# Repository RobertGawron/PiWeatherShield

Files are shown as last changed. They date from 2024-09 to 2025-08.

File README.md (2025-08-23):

# Pi Weather Shield



## Purpose

Low-cost, easy-to-build hat Raspberry Pi that turns it into an indoor weather station. On the hardware side, it's a simple PCB with sensors I2C parts (BME280 and Si7021) and a small OLED screen to show the meassurements: temperature, humidity, and air pressure. On the software side there is a Rust app that handles the data and can send them via MQTT for furthr processing (using tools like Graphana and Home asistant).

The project can be integrated with the [Home Environment Monitor](https://github.com/RobertGawron/HomeEnvironmentMonitor), adding real-time graphs of the meassurements accessible from phone or PC.

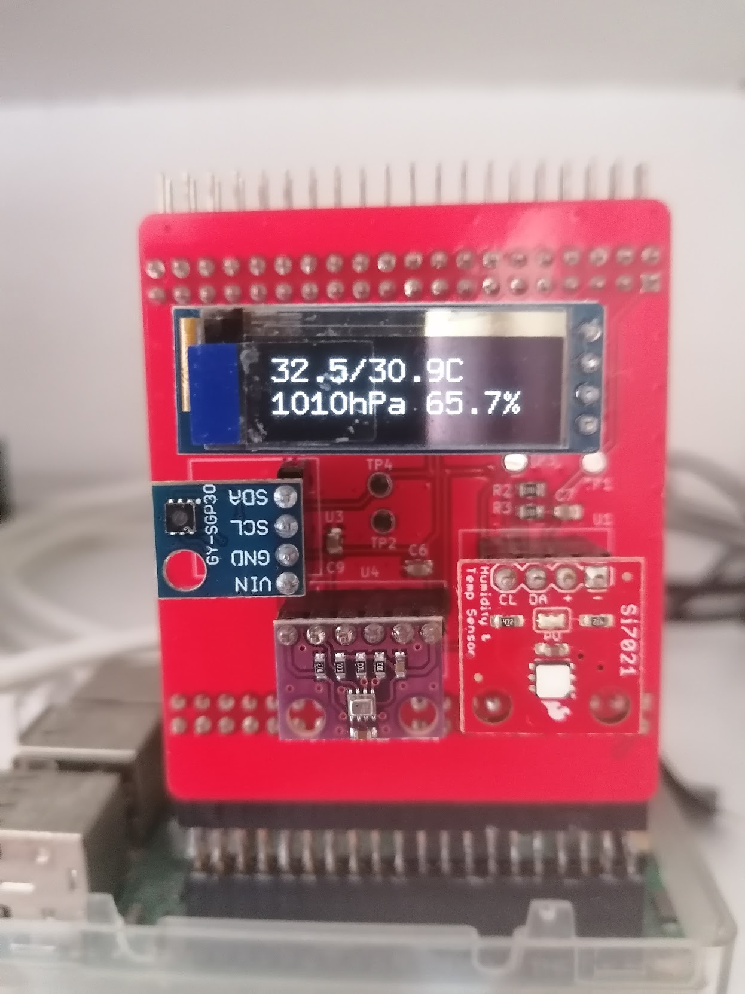
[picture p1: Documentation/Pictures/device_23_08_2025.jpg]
Picture of the device


## Hardware

This project is straightforward and includes the following I2C components:

* **Si7021:**
    * Temperature
    * Relative humidity
* **SGP30:**
    * TVOC (Total Volatile Organic Compounds)
    * eCO2 (equivalent CO2)
    * Raw hydrogen (H2) signal
    * Raw ethanol signal
* **BME280:**
    * Temperature
    * Relative humidity
    * Atmospheric pressure
* **SSD1306:** 0.91-inch 128x32 OLED display.

Circuit of the device

Tools: KiCad.

[More info.](./Hardware/README.md)

## Installation

The application is quite simple (just a couple of Python scripts) and could easily be developed directly on the Raspberry Pi, which is probably what most people would do for a small project like this. However, I’ve chosen a different approach -one that might seem like overkill- but it allows me to learn and apply DevOps.

We'll set up a local Docker environment capable of cross-compiling Docker images that contain our application, which will then be deployed to the Raspberry Pi.

Using Ansible, we will preconfigure the Raspberry Pi (install Docker, enable I2C, etc.) and deploy the Docker images to the Pi automatically.

[More info.](./DevOps/README.md)

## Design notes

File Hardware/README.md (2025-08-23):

## Hardware Overview

#### I2C Addresses:

* Si7021: 0x40
* SGP30: 0x58
* BME280:
    * 0x76 (when the SDO pin is grounded)
    * 0x77 (when the SDO pin is connected to VCC)
* SSD1306: 0x3C or 0x3D, depending on the PCB design.

## Tools

The PCB diagram was designed using KiCad.

## Links

* [Raspberry Pi pinout](https://www.raspberrypi.com/documentation/computers/images/GPIO-Pinout-Diagram-2.png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)

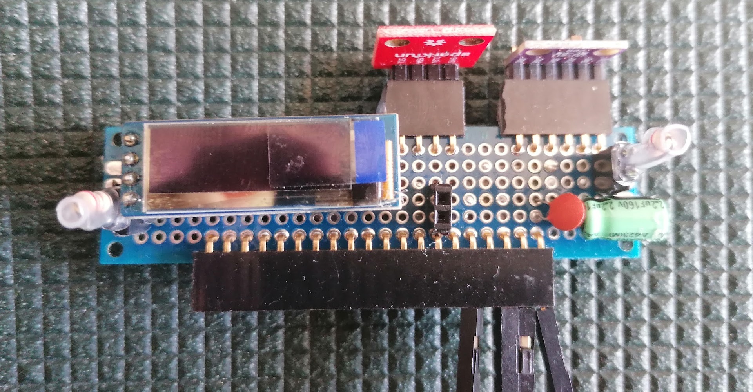
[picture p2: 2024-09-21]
Documentation/Pictures/device_21_09_2024.jpg

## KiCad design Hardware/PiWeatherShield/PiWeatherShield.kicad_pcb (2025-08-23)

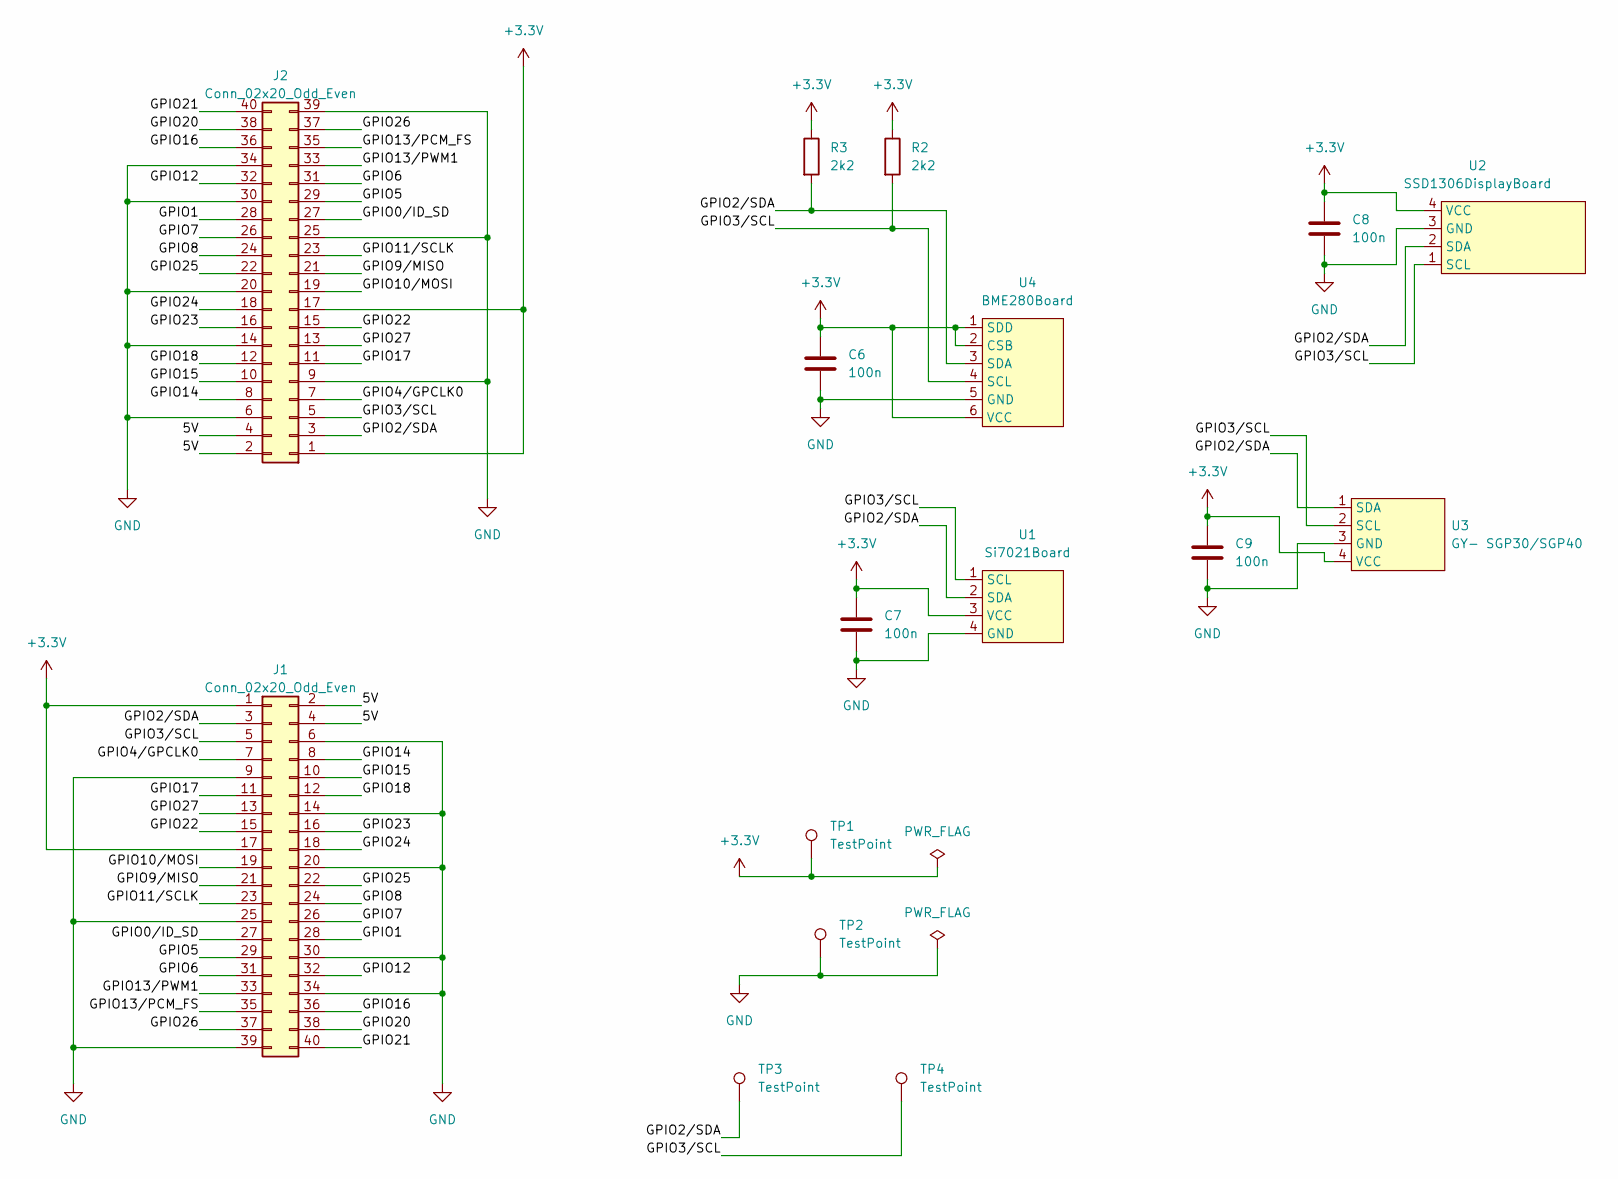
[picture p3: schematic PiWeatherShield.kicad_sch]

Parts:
C6, C7, C8, C9: 100n; C_0805_2012Metric
J1: Conn_02x20_Odd_Even; PinSocket_2x20_P2.54mm_Horizontal
J2: Conn_02x20_Odd_Even; PinHeader_2x20_P2.54mm_Horizontal
R2, R3: 2k2; R_0805_2012Metric
TP1, TP2, TP3, TP4: TestPoint; TestPoint_Pad_D2.0mm
U1: Si7021Board; SIP-4
U2: SSD1306DisplayBoard
U3: GY- SGP30/SGP40; GY- SGP30SGP40
U4: BME280Board

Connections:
+3.3V: C6.1, C7.1, C8.1, C9.1, J1.1, J1.17, J2.1, J2.17, R2.1, R3.1, TP1.1, U1.3 (VCC), U2.4 (VCC), U3.4 (VCC), U4.1 (SDD), U4.2 (CSB), U4.6 (VCC)
/5V: J1.2, J1.4, J2.2, J2.4
/GPIO0/ID_SD: J1.27, J2.27
/GPIO1: J1.28, J2.28
/GPIO2/SDA: J1.3, J2.3, R3.2, TP3.1, U1.2 (SDA), U2.2 (SDA), U3.1 (SDA), U4.3 (SDA)
/GPIO3/SCL: J1.5, J2.5, R2.2, TP4.1, U1.1 (SCL), U2.1 (SCL), U3.2 (SCL), U4.4 (SCL)
/GPIO4/GPCLK0: J1.7, J2.7
/GPIO5: J1.29, J2.29
/GPIO6: J1.31, J2.31
/GPIO7: J1.26, J2.26
/GPIO8: J1.24, J2.24
/GPIO9/MISO: J1.21, J2.21
/GPIO10/MOSI: J1.19, J2.19
/GPIO11/SCLK: J1.23, J2.23
/GPIO12: J1.32, J2.32
/GPIO13/PCM_FS: J1.35, J2.35
/GPIO13/PWM1: J1.33, J2.33
/GPIO14: J1.8, J2.8
/GPIO15: J1.10, J2.10
/GPIO16: J1.36, J2.36
/GPIO17: J1.11, J2.11
/GPIO18: J1.12, J2.12
/GPIO20: J1.38, J2.38
/GPIO21: J1.40, J2.40
/GPIO22: J1.15, J2.15
/GPIO23: J1.16, J2.16
/GPIO24: J1.18, J2.18
/GPIO25: J1.22, J2.22
/GPIO26: J1.37, J2.37
/GPIO27: J1.13, J2.13
GND: C6.2, C7.2, C8.2, C9.2, J1.6, J1.9, J1.14, J1.20, J1.25, J1.30, J1.34, J1.39, J2.6, J2.9, J2.14, J2.20, J2.25, J2.30, J2.34, J2.39, TP2.1, U1.4 (GND), U2.3 (GND), U3.3 (GND), U4.5 (GND)

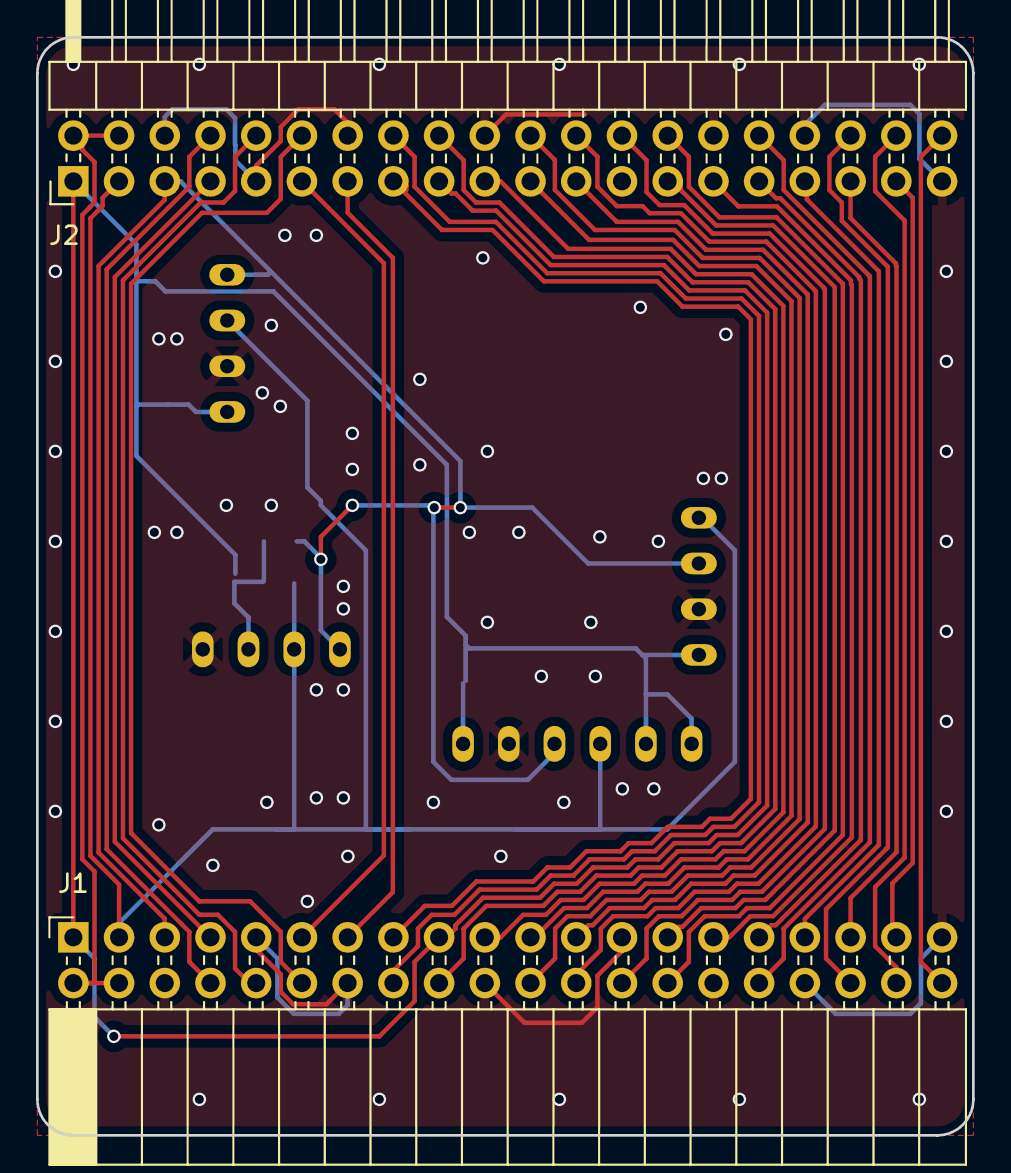
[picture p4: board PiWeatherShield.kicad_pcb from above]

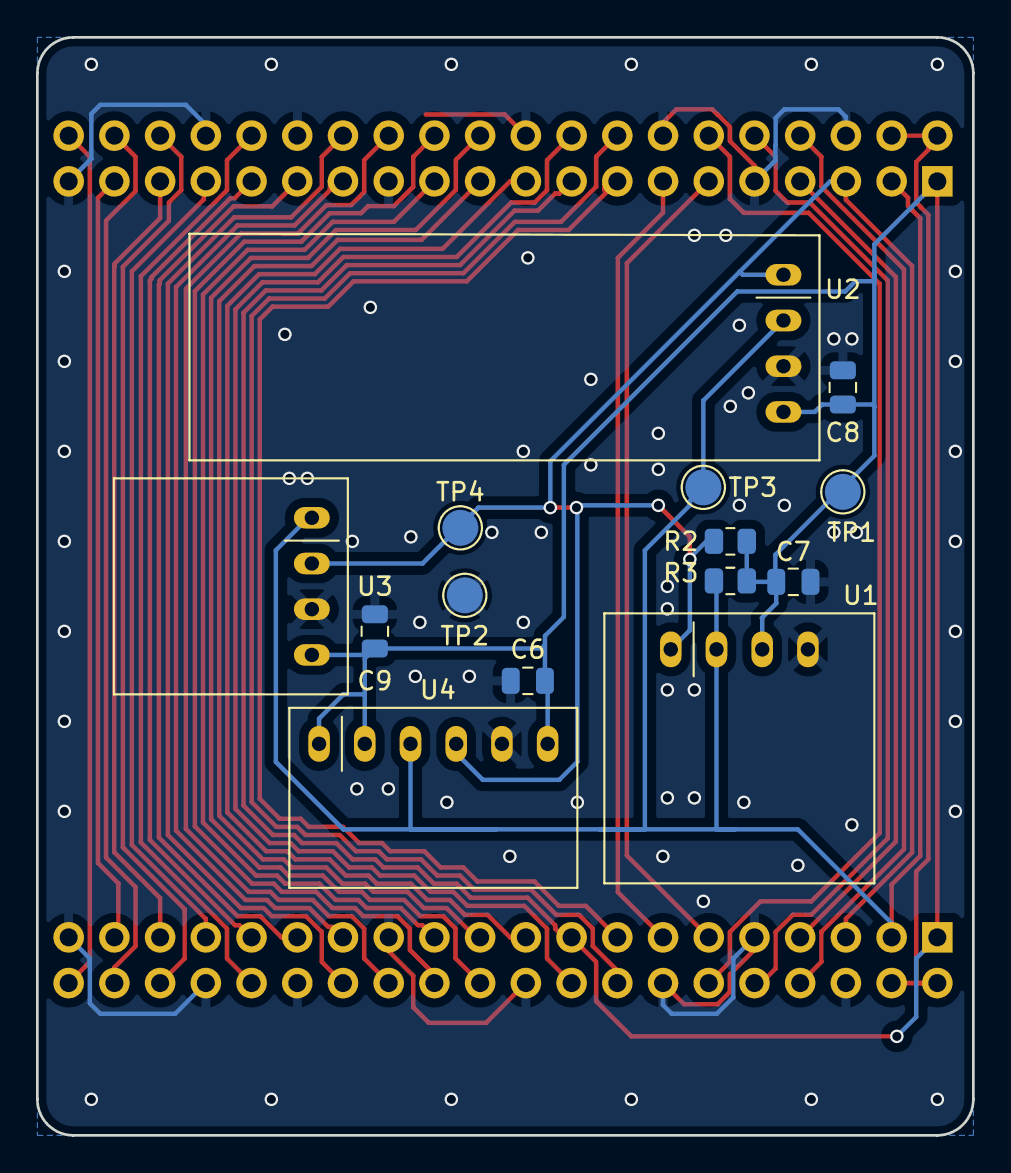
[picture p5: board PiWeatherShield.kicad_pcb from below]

Board: 2 copper layers, 52.0 x 61.0 mm, 16 parts (14 on the bottom side), 31 nets.

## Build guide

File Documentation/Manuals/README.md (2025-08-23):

# Development Environment Setup and Deployment

## Tools You Will Need:

* [Raspberry Pi Imager](https://www.raspberrypi.com/software/)
* [Docker](https://www.docker.com/products/docker-desktop/)

# Seting up Rasberry Pi

This section is only for setting up a fresh SD card. If your Raspberry Pi is already configured, and you can connect to it remotely via SSH, you can skip this.

* Flash Raspberry Pi OS onto the SD Card
Use Raspberry Pi Imager to install the OS (choose the Lite version for faster installation).
During setup, select Advanced Options to configure your username, password, and Wi-Fi access.
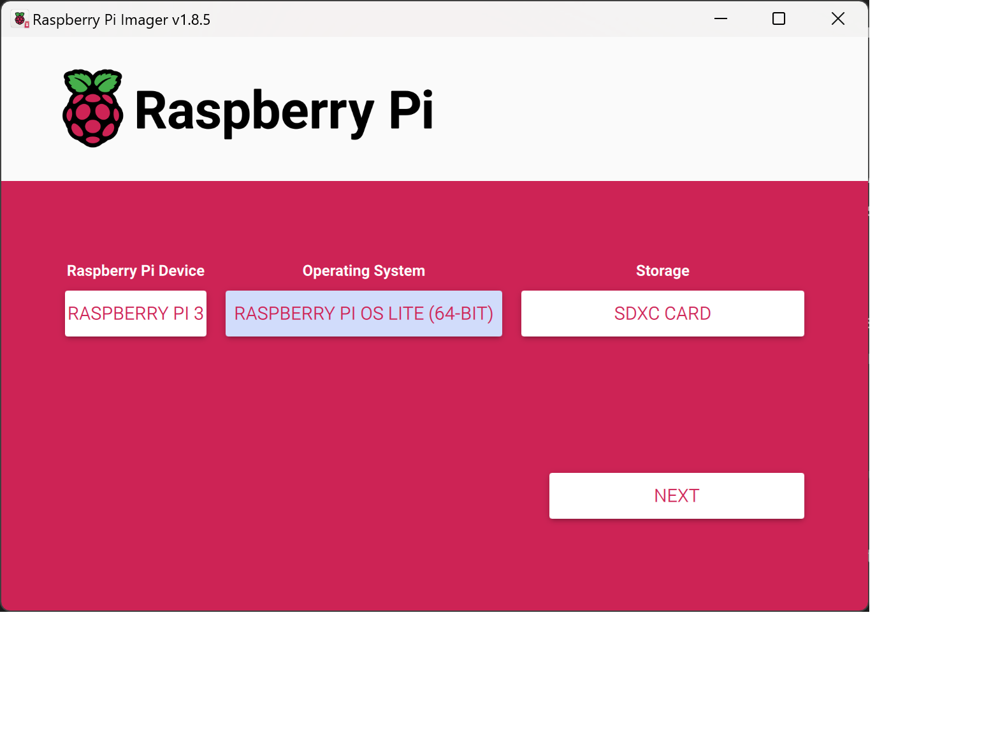
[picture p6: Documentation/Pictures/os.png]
Pi Image to be flashed

* [(Optional) Backup Your SD Card](https://www.makeuseof.com/how-to-back-up-your-raspberry-pi-sd-card-on-windows/
)
* Find the Raspberry Pi’s IP Address. I've used Wireshark:
    * Power off your Raspberry Pi.
    * Start Wireshark and use the capture filter: bootp or dhcp to capture DHCP requests.
    * Power on your Raspberry Pi. The IP address will appear in the Wireshark logs.
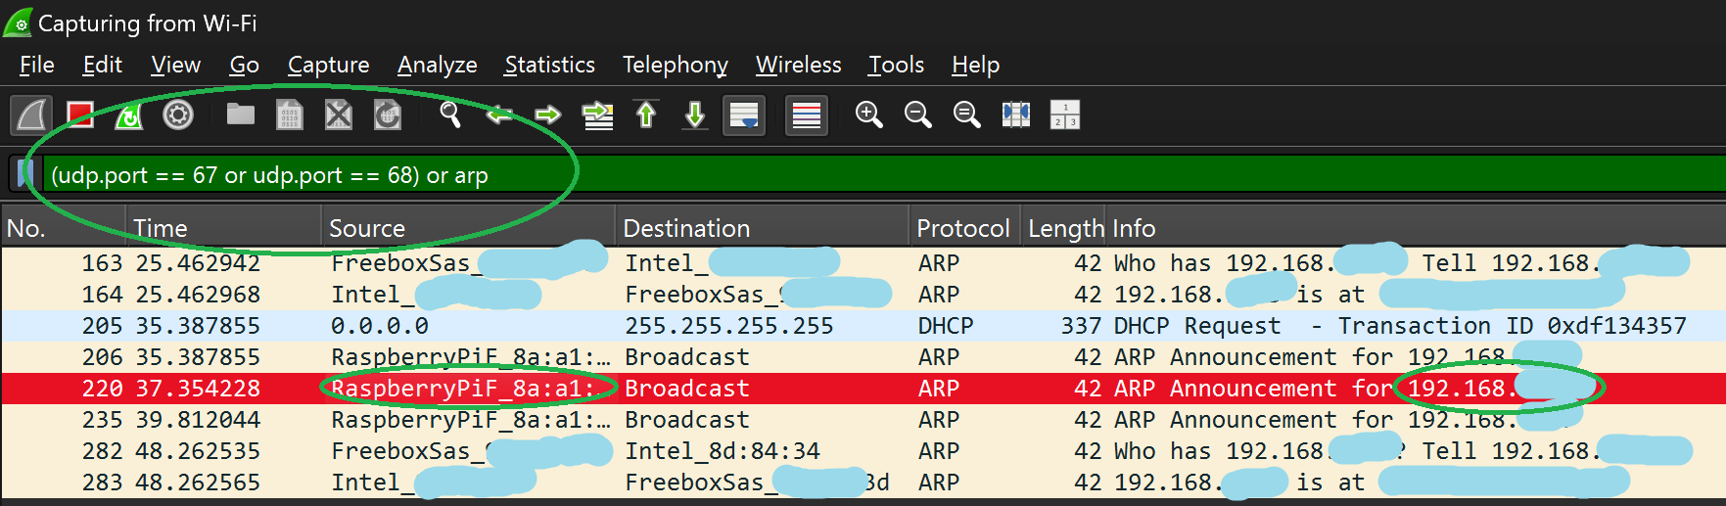
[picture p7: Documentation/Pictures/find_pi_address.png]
Finding IP of Rasberry Pi in local network
    

4. Connect via SSH
Connect to the Raspberry Pi using SSH using credential you set-up while flashing the SD card:
```ssh <username>@<raspberry_pi_ip_address>```

### Notes:
If the Wi-Fi setup fails:
* Manually create a wpa_supplicant.conf file and place it in the root folder of the SD card.
Windows users: ensure there is no hidden .txt extension.
* To find your Wi-Fi SSID (network name) and password on a Windows PC, you can [follow these instructions](https://www.hellotech.com/guide/for/how-to-find-wifi-password-windows-10).

## Setting local development environment

docker-compose build

LOCAL_UID=$(id -u) LOCAL_GID=$(id -g) docker-compose up -d
//docker-compose run --service-ports atmosphere-pi

docker-compose exec atmosphere-pi bash

docker-compose down --remove-orphans

code coverage
cargo tarpaulin --workspace --out Html --output-dir target/coverage

# UML generation

docker pull plantuml/plantuml-server:jetty

docker run -d -p 8080:8080 plantuml/plantuml-server:jetty

For more details:
https://plantuml.com/starting

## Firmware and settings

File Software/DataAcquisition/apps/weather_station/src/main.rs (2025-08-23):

use linux_embedded_hal::{Delay, I2cdev};
use ssd1306::I2CDisplayInterface;

use application::{Reading, Sensor, SensorReading, SensorType};
use domain::SensorDataCollector;
use drivers::{Bme280Sensor, CsvSink, OledDisplay, Si7021Sensor, StdOutSink};
use ssd1306::prelude::I2CInterface;

use embedded_hal::delay::DelayNs;

use application::AnySink;

fn get_timestamp_ms() -> u64 {
        std::time::SystemTime::now()
            .duration_since(std::time::UNIX_EPOCH)
            .unwrap_or_default()
            .as_millis() as u64
}

fn main() -> Result<(), Box<dyn std::error::Error>> {
    // Initialize I2C bus
    let i2c = I2cdev::new("/dev/i2c-1").map_err(|e| Box::new(e) as Box<dyn std::error::Error>)?;

    // Initialize OLED display
    let interface = I2CDisplayInterface::new(i2c);
    let display_sink =
        OledDisplay::new(interface).map_err(|e| Box::new(e) as Box<dyn std::error::Error>)?;

    // Initialize sensors
    // BME280 uses the same I2C bus, so we need to clone it or open a new handle
    let i2c_bme =
        I2cdev::new("/dev/i2c-1").map_err(|e| Box::new(e) as Box<dyn std::error::Error>)?;
    let mut bme_sensor = Bme280Sensor::new_secondary(i2c_bme)
        .map_err(|e| Box::new(e) as Box<dyn std::error::Error>)?;

    let i2c_si =
        I2cdev::new("/dev/i2c-1").map_err(|e| Box::new(e) as Box<dyn std::error::Error>)?;
    let mut si_sensor = Si7021Sensor::new(i2c_si); // Si7021Sensor::new does not return Result, so no map_err needed here.

    let stdout_sink = StdOutSink;

    let mut delay = Delay;
    let csv_sink = CsvSink::open("readings.csv")?;

    let mut sensor_collector: SensorDataCollector<
        AnySink<
            CsvSink<std::io::BufWriter<std::fs::File>>,
            StdOutSink,
            OledDisplay<I2CInterface<I2cdev>>,
        >,
        3,
    > = SensorDataCollector::new();

    // Add sinks wrapped in AnySink enum
    sensor_collector
        .add_sink(AnySink::Csv(csv_sink))
        .map_err(|_| "Failed to add CSV sink")?;
    sensor_collector
        .add_sink(AnySink::Stdout(stdout_sink))
        .map_err(|_| "Failed to add stdout sink")?;
    sensor_collector
        .add_sink(AnySink::Oled(display_sink))
        .map_err(|_| "Failed to add OLED sink")?;

    loop {
        // Read data from sensors
        let bme_data_raw = bme_sensor
            .read()
            .map_err(|e| Box::new(e) as Box<dyn std::error::Error>)?;
        let si_data_raw = si_sensor
            .read()
            .map_err(|e| Box::new(e) as Box<dyn std::error::Error>)?;

        let mut reading = Reading::new(get_timestamp_ms());

        // Add BME280 sensor readings
        if let Some(temp) = bme_data_raw.get_temperature(Some(application::SensorId::Bme280)) {
            reading
                .add_sensor(SensorReading {
                    sensor_type: SensorType::Temperature,
                    value: temp,
                    unit: application::Unit::Celsius,
                    sensor_id: application::SensorId::Bme280,
                })
                .ok();
        }
        if let Some(humid) = bme_data_raw.get_humidity(Some(application::SensorId::Bme280)) {
            reading
                .add_sensor(SensorReading {
                    sensor_type: SensorType::Humidity,
                    value: humid,
                    unit: application::Unit::Percent,
                    sensor_id: application::SensorId::Bme280,
                })
                .ok();
        }
        if let Some(pres) = bme_data_raw.get_pressure() {
            reading
                .add_sensor(SensorReading {
                    sensor_type: SensorType::Pressure,
                    value: pres,
                    unit: application::Unit::HectoPascal,
                    sensor_id: application::SensorId::Bme280,
                })
                .ok();
        }

        // Add Si7021 sensor readings
        if let Some(temp) = si_data_raw.get_temperature(Some(application::SensorId::Si7021)) {
            reading
                .add_sensor(SensorReading {
                    sensor_type: SensorType::Temperature,
                    value: temp,
                    unit: application::Unit::Celsius,
                    sensor_id: application::SensorId::Si7021,
                })
                .ok();
        }
        if let Some(humid) = si_data_raw.get_humidity(Some(application::SensorId::Si7021)) {
            reading
                .add_sensor(SensorReading {
                    sensor_type: SensorType::Humidity,
                    value: humid,
                    unit: application::Unit::Percent,
                    sensor_id: application::SensorId::Si7021,
                })
                .ok();

            // Distribute reading to all sinks
            sensor_collector.distribute(&reading).map_err(|errors| {
                let error_msgs: Vec<String> = errors
                    .into_iter()
                    .map(|(idx, err)| format!("Sink {} failed: {}", idx, err))
                    .collect();
                format!("Distribution failed: {}", error_msgs.join(", "))
            })?;
        }

        // Delay for a period
        delay.delay_ms(5000_u32);
    }
}

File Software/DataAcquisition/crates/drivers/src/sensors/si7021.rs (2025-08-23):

use linux_embedded_hal::Delay;
use si7021_t_rh as si7021;

use application::Sensor;
use application::{Reading, SensorReading, SensorType, Unit, SensorId};
use core::fmt; // Import fmt for manual Display/Debug implementations

// Define a new error type that wraps the si7021_t_rh error
pub enum Si7021Error<E> {
    /// Error from the underlying I2C bus
    I2c(E),
    /// Error from the si7021-t-rh driver
    Driver(si7021::error::Error<E>),
}

// Manual implementation of Debug for Si7021Error
impl<E: fmt::Debug> fmt::Debug for Si7021Error<E> {
    fn fmt(&self, f: &mut fmt::Formatter<'_>) -> fmt::Result {
        match self {
            Si7021Error::I2c(e) => f.debug_tuple("Si7021Error::I2c").field(e).finish(),
            Si7021Error::Driver(e) => f.debug_tuple("Si7021Error::Driver").field(e).finish(),
        }
    }
}

impl<E: fmt::Debug + fmt::Display> fmt::Display for Si7021Error<E> {
    fn fmt(&self, f: &mut fmt::Formatter<'_>) -> fmt::Result {
        match self {
            Si7021Error::I2c(e) => write!(f, "I2C error: {}", e),
            // Fix: Use debug formatter for the inner driver error as it doesn't implement Display
            Si7021Error::Driver(e) => write!(f, "Si7021 driver error: {:?}", e),
        }
    }
}

// Conditionally implement std::error::Error for compatibility with Box<dyn std::error::Error>
#[cfg(feature = "std")]
impl<E> std::error::Error for Si7021Error<E> where E: std::error::Error + 'static {}

// Implement From trait to allow easy conversion from the driver's error
impl<E> From<si7021::error::Error<E>> for Si7021Error<E> {
    fn from(e: si7021::error::Error<E>) -> Self {
        Si7021Error::Driver(e)
    }
}

pub struct Si7021Sensor<I2C> {
    inner: si7021::Si7021<I2C, Delay>, // driver uses hal-1.0 traits
}

impl<I2C, E> Si7021Sensor<I2C>
where
    I2C: embedded_hal::i2c::I2c<Error = E>,
{
    pub fn new(i2c: I2C) -> Self {
        Self {
            inner: si7021::Si7021::new(i2c, Delay),
        }
    }
}

impl<I2C, E> Sensor for Si7021Sensor<I2C>
where
    I2C: embedded_hal::i2c::I2c<Error = E>,
    E: core::fmt::Debug + core::fmt::Display + 'static, // Ensure E implements Debug and Display
{
    type Error = Si7021Error<E>; // Use the new error type
    fn read(&mut self) -> Result<Reading, Self::Error> {
        let t = self.inner.read_temperature().map_err(Si7021Error::Driver)?;
        let h = self
            .inner
            .read_relative_humidity()
            .map_err(Si7021Error::Driver)?;

        let mut reading = Reading::new(0);

        reading
            .add_sensor(SensorReading {
                sensor_type: SensorType::Temperature,
                value: t,
                unit: Unit::Celsius,
                sensor_id: SensorId::Si7021,
            })
            .ok();
        reading
            .add_sensor(SensorReading {
                sensor_type: SensorType::Humidity,
                value: h,
                unit: Unit::HectoPascal,
                sensor_id: SensorId::Si7021,
            })
            .ok();
        Ok(reading)
    }
}

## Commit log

2024-09-07 fix: #3
    [PiWeatherShield.kicad_pcb, PiWeatherShield.kicad_sch]
2024-09-21 build docker containers for rasbbery pi's in docker build container
    [PiWeatherShield.kicad_pcb, PiWeatherShield.kicad_sch]
2025-08-23 init version
    [PiWeatherShield.kicad_pcb, PiWeatherShield.kicad_sch]
